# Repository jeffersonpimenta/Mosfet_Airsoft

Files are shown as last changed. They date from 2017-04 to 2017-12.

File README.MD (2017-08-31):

# Gatilho eletrônico para AEGs

Uma opção às encontradas no mercado brasileiro, custo inferior sem perca de qualidade!

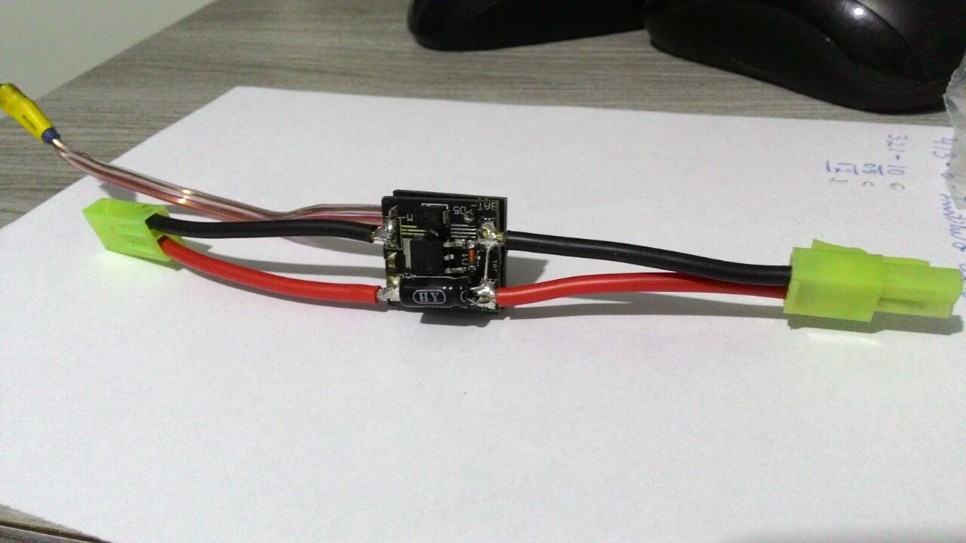
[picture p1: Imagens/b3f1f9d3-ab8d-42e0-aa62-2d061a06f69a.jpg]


## Modos de funcionamento

1. Modo espelhamento: Não faz nenhuma programação no modo de disparo.
2. Modo rajada: Cada toque dispara n tiros configurados
3. Modo econômico: Cada rajada dispara apenas n tiros configurados

## Como configurar

1. Segure o gatilho e conecte a bateria
2. Ao ouvir o primeiro bipe, aperte o gatilho de acordo com o modo desejado (1, 2 ou 3).
3. Segure o gatilho até ouvir um bipe contínuo para confirmar.
4. Se o modo configurado for o 2 ou o 3, precisamos configurar a quantidade de disparos! Ponha a arma no semi-automático e dê dois disparos. Um bipe será ouvido quando a operação for concluída.
5. Aperte o gatilho de acordo com a quantidade de disparos configuradas.
6. Segure até ouvir um bipe contínuo.
7. Feito!

A demonstração pode ser vista [aqui](https://www.youtube.com/watch?v=d0rjX8GWv6M&t=5s)

## Quais as vantagens em relação ao gatilho stock da AEG?

- [x] Evita o desgaste prematuro dos contatos mecânicos
- [x] Leve ganho de cadência
- [x] Uma leve economia de bateria
- [x] Controle total dos disparos

## Arquivos e fotos

* /BRD - Esquemático e desenho da placa
A placa pode ser comprada [aqui](https://www.curtacircuitos.com.br/jeffersonpimenta/Gatilho) 
* /CODE - [Código fonte](https://github.com/jeffersonpimenta/Mosfet_Airsoft/tree/master/Code)
* /Imagens - [Fotos](https://github.com/jeffersonpimenta/Mosfet_Airsoft/tree/master/Imagens)

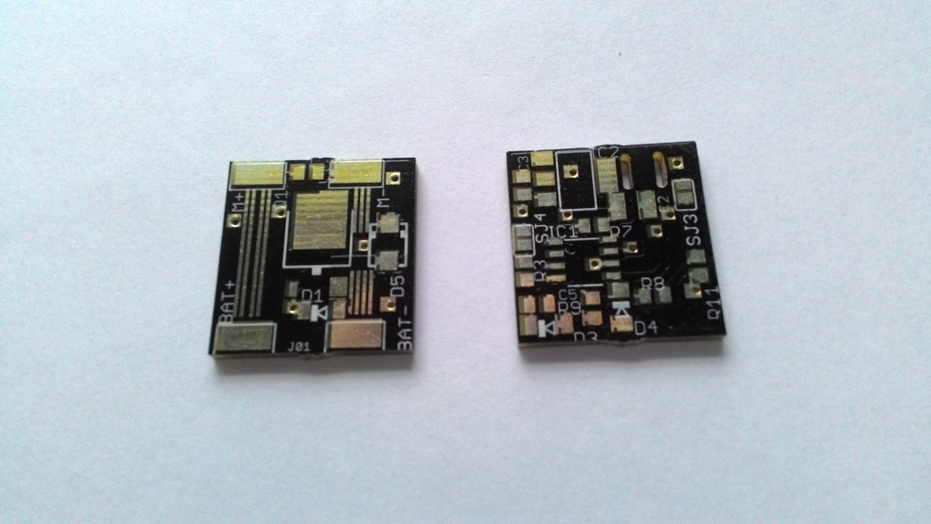
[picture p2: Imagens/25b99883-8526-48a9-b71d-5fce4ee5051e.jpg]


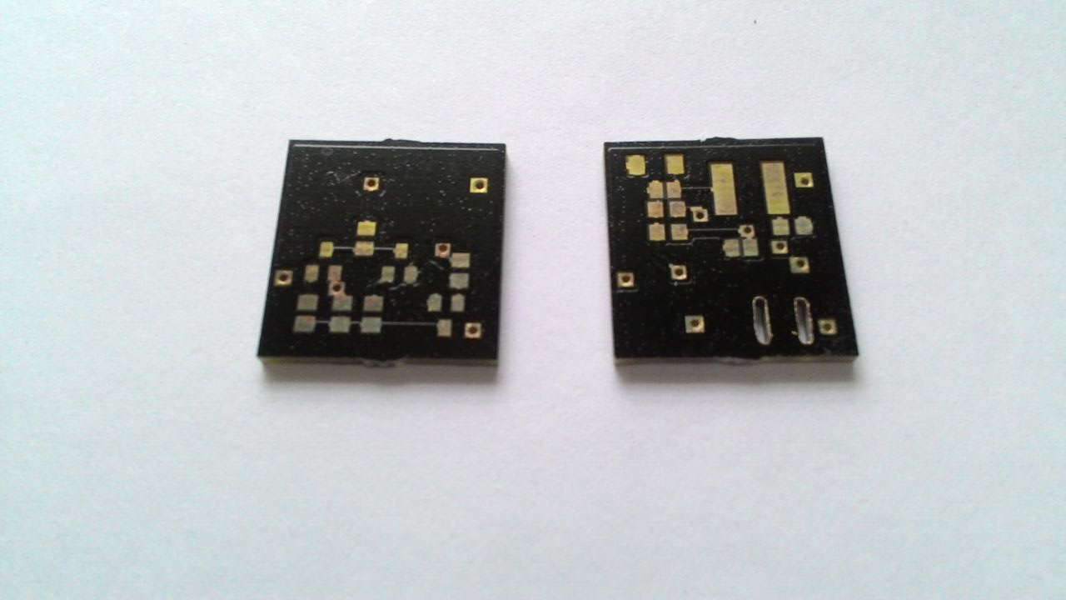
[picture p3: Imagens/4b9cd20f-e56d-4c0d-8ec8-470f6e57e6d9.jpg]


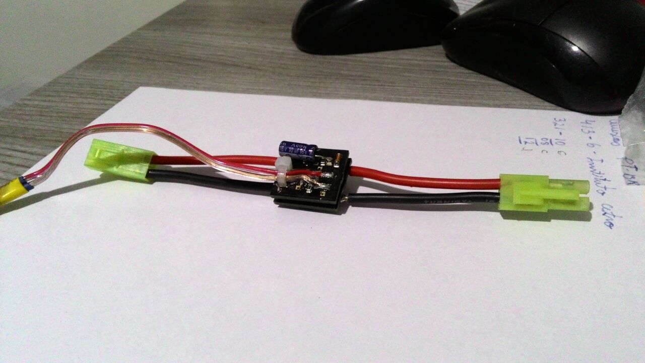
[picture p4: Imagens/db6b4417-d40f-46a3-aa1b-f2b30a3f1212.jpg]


A placa pode ser encomendada pelo link https://www.curtacircuitos.com.br/jeffersonpimenta/Gatilho 

Custa apenas 8,82 reais a unidade e abaixo uma imagem das placas produzidas.

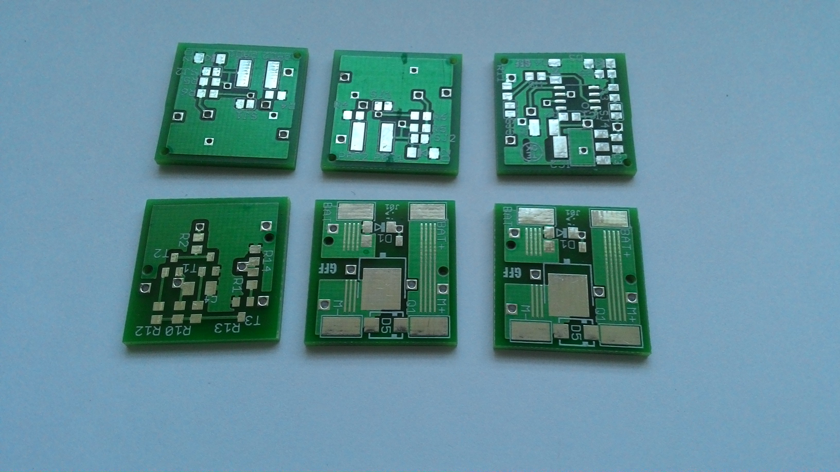
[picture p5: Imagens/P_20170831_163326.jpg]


# Observações
* O microcontrolador que deve ser utilizado tem referência Attiny85, não o Attiny13 como mostrado no esquemático, apenas uma falta da biblioteca para o dispositivo. Ambos são da mesma família e possuem a mesma pinagem
* Utilizar Atmel Studio 7.0

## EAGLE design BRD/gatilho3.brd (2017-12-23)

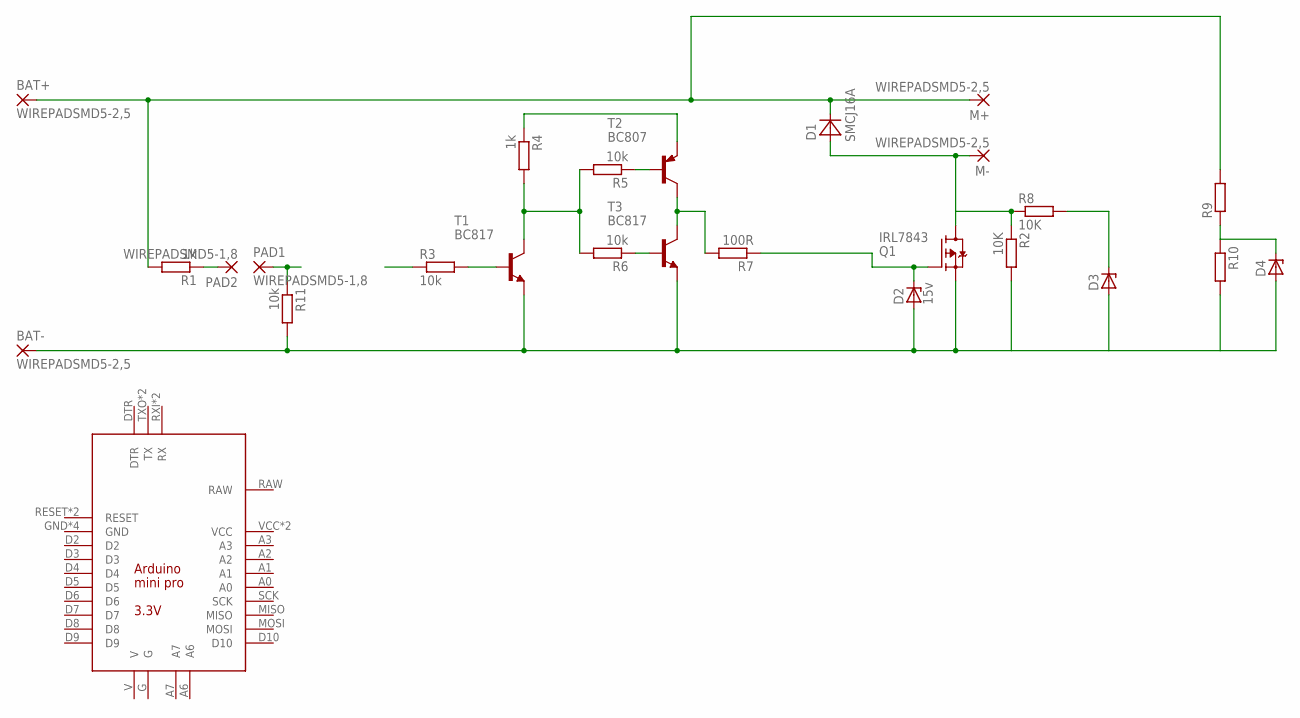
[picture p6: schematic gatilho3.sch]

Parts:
BAT+: WIREPADSMD5-2,5; 5-2,5
BAT-: WIREPADSMD5-2,5; 5-2,5
D1: SMCJ16A; SMA
D2: 15v; SOD80C
D3, D4: ZENER-DIODESOD80C; SOD80C
M+: WIREPADSMD5-2,5; 5-2,5
M-: WIREPADSMD5-2,5; 5-2,5
PAD1, PAD2: WIREPADSMD5-1,8; 5-1,8
Q1: IRL7843; TO252
R1, R4: 1k; R0805
R2, R8: 10K; R0805
R3, R5, R6, R11: 10k; R0805
R7: 100R; R0805
R9, R10: R-EU_R0805; R0805
T1, T3: BC817; SOT23-BEC
T2: BC807; SOT23-BEC
U$1: ARDUINO_MINI_PRO_3V3

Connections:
unnamed: BAT-.1, D2.A, D3.A, D4.A, Q1.2 (S), R2.2, R10.2, R11.2, T1.E, T3.E
unnamed: D1.A, M-.1, Q1.3 (D), R2.1, R8.1
unnamed: D4.C, R9.1, R10.1
unnamed: PAD2.1, R1.1
unnamed: BAT+.1, D1.C, M+.1, R1.2, R9.2
unnamed: PAD1.1, R11.1
unnamed: D3.C, R8.2
unnamed: R4.1, T2.E
unnamed: R4.2, R5.2, R6.2, T1.C
unnamed: R3.2, T1.B
unnamed: R7.2, T2.C, T3.C
unnamed: R5.1, T2.B
unnamed: R6.1, T3.B
unnamed: D2.C, Q1.1 (G), R7.1

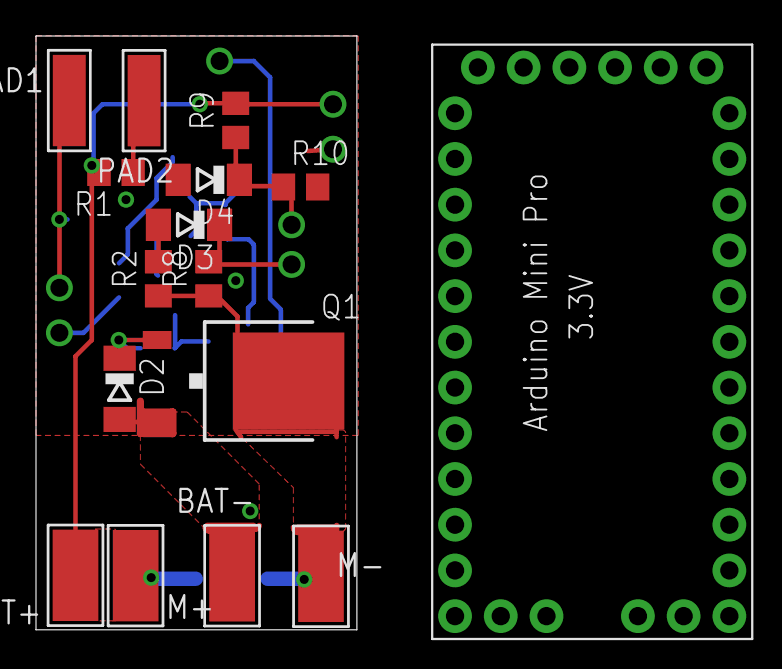
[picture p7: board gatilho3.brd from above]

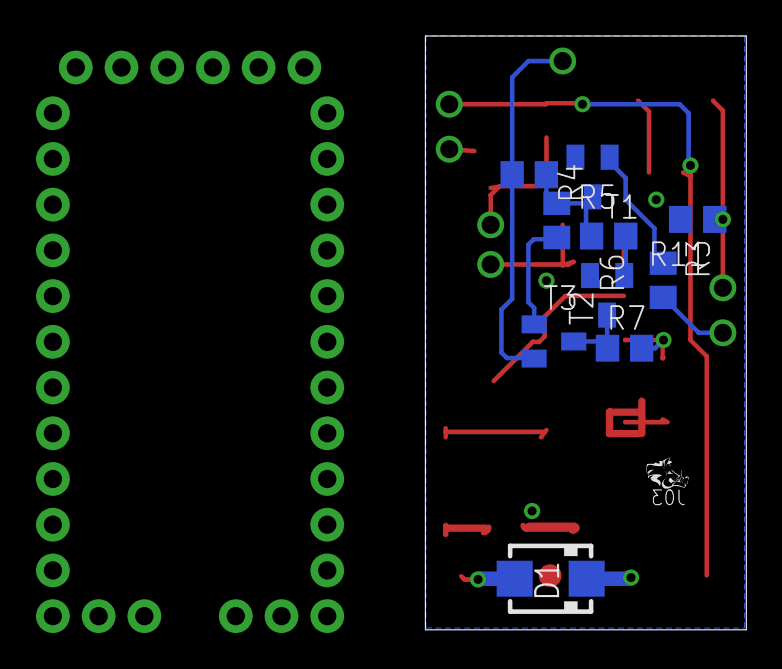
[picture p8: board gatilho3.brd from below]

Board: 2 copper layers, 17.8 x 33.0 mm, 26 parts (10 on the bottom side), 14 nets.

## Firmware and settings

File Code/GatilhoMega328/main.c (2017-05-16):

/*
 * GatilhoMega328.c
 *
 * Created: 12/01/2017 22:06:59
 * Author : Jéfferson
 */ 

//#define F_CPU 9600000UL

#define bit_get(p,m) ((p) & _BV(m))
#define bit_set(p,m) ((p) |= _BV(m))
#define bit_clear(p,m) ((p) &= ~_BV(m))

#include "util/delay.h"
#include <avr/io.h>
#include <avr/pgmspace.h>

#define Ptrigger DDRB
#define Trigger PINB
#define Pintrigger PB1//porta do gatilho

#define Omotor DDRB
#define Motor PORTB
#define Pinmotor PB0//porta do controle do motor

#define atraso 0.9

#define  debouncedelay 5

uint8_t tiros,timeon,firemode=0;//variáveis que deverão ficar na eeprom
uint8_t i,check=0;//seta variáveis

int main(void)
{

	bit_clear(Ptrigger,Pintrigger);//seta ddr do gatilho como entrada
	bit_set(Omotor,Pinmotor);//seta ddr do motor como saída
	bit_clear(Motor,Pinmotor);//garante que o motor ficará desligado
	barulho();
	_delay_ms(200);
	barulho();
	
	
while(1){
	check=0;
	do
	{
		check++;
		_delay_ms(4);
	} while (!bit_get(Trigger,Pintrigger) && (check<200));
	
	if (check<200)
	{
		tiros=eeprom_read_byte((uint8_t*)10);//lê a quantidade de tiros configuradas
		timeon=eeprom_read_byte((uint8_t*)11);//carrega o tempo de tiro da memória
		firemode=eeprom_read_byte((uint8_t*)12);//lê a quantidade de tiros configuradas		
		normal();//funcionamento normal
	}else
	{
		conf();//entra no modo de configuração
	}
}	
	
	
	

}


void normal(){
	uint8_t j=0,i=0;//declara contador
		
		if (firemode==1)
		{
			while(1){
						if (bit_get(Trigger,Pintrigger))
						{
							bit_clear(Motor,Pinmotor);
						}else{
							bit_set(Motor,Pinmotor);
						}
					}
		}//modo de espelhamento do estado do gatilho
		
		
		if (firemode==2){//modo economico
			while(1){
				i=0;
				_delay_ms(1);
				while(!bit_get(Trigger,Pintrigger)){//detecta gatilho pressionado
					i++;
					_delay_ms(1);
					if (i>debouncedelay)
					{
						bit_set(Motor,Pinmotor);//liga motor
						
						if ((!bit_get(Trigger,Pintrigger))){
							for (i=0;i<tiros;i++)//quantidade de tiros menos o efetuado
							{
								
							if (i==0)
								{//primeiro tiro, de aceleração
									for (j=0;j<timeon;j++)
									{
										_delay_ms(1);
									}//tempo que cada ciclo leva pra se completar									
									}else{
									
									if (bit_get(Trigger,Pintrigger)) break;//para se o usuário parar os tiros	
										
									for (j=0;j<(timeon*atraso);j++)
									{
										_delay_ms(1);
									}//tempo que cada ciclo leva pra se completar									
									}//segundo tiro, motor acelerado

								}
							bit_clear(Motor,Pinmotor);//desliga motor, pois os tiros configurados foram efetuados						
	
							do 
							{
								_delay_ms(1);
							} while (!bit_get(Trigger,Pintrigger));//espera o gatilho ser liberado
							
							
						}
					}else bit_clear(Motor,Pinmotor);//desliga motor
				}	
			}
		}
		
		
		if (firemode==3)//modo rambo
		{
			while(1){
				i=0;				
				_delay_ms(1);
				while(!bit_get(Trigger,Pintrigger)){//detecta gatilho pressionado
					i++;
					_delay_ms(1);
					if (i>debouncedelay)
					{
						bit_set(Motor,Pinmotor);//liga motor
						
						if ((!bit_get(Trigger,Pintrigger))){
							for (i=0;i<tiros;i++)//quantidade de tiros efetuado
							{
								if (i==0)
								{//primeiro tiro, de aceleração
																	
									for (j=0;j<timeon;j++)
									{
										_delay_ms(1);
									}//tempo que cada ciclo leva pra se completar
									}else{
									for (j=0;j<(timeon*atraso);j++)
									{
										_delay_ms(1);
									}//tempo que cada ciclo leva pra se completar
								}//segundo tiro, motor acelerado
							}
							
							while(!bit_get(Trigger,Pintrigger)){
								for (j=0;j<(timeon*atraso);j++)
								{
									_delay_ms(1);
								}//tempo que cada ciclo leva pra se completar								
							}
							bit_clear(Motor,Pinmotor);//desliga motor
						
					}
				}else bit_clear(Motor,Pinmotor);//desliga motor
			}
		}	
	}
}



void conf(){
	uint8_t flag=1;
	
	
	firemode=0;//limpa firemode
	flag=1;//reseta flag

	do
	{
		barulho();
	} while (!bit_get(Trigger,Pintrigger));	//espera usuário parar de apertar pra entrar no menu

	
	do
	{
		i=0;//reseta variavel
		while(!bit_get(Trigger,Pintrigger)){
			i++;
			_delay_ms(100);
			if (i>30)//quebra o loop se o gatilho for pressionado
			{
				flag=0;//sinaliza final da função
				if (firemode>3) firemode=1;
				if (firemode==0) firemode=1;//evita treta
				eeprom_write_byte((uint8_t*) 12, firemode);//grava na memo
				break;
			}
		}//conta o tempo que o gatilho foi apertado

		if (i>2)//debounce
		{
			if (i>30)//maior que 4 segundos
			{
				for (i=0;i<firemode;i++)
				{
					barulho();
					_delay_ms(500);//indica o modo configurado
				}
				
				}else{
				firemode++;
			}
		}
	} while (flag);//loop de configuração do modo	


	do
	{
		barulho();
	} while (!bit_get(Trigger,Pintrigger));	//espera usuário parar de apertar pra sair do menu
	
	if (firemode!=1)
	{
		
		flag=1;//seta flag do loop

		
		do{
			i=0;
			while(!bit_get(Trigger,Pintrigger)){//detecta gatilho pressionado
				i++;
				_delay_ms(1);
				if (i>debouncedelay)
				{
					bit_set(Motor,Pinmotor);//liga motor
					do
					{
						i++;
						_delay_ms(1);
					} while (!bit_get(Trigger,Pintrigger));
					bit_clear(Motor,Pinmotor);//desliga motor
					flag=0;
				}
			}//dois tiros pra configurar o tempo de tiro
			
			}while(flag);
			
		
		flag=1;//seta flag do loop
		do 
		{
				i=0;
				while(!bit_get(Trigger,Pintrigger)){//detecta gatilho pressionado
					i++;
					_delay_ms(1);
					if (i>debouncedelay)
					{			
						bit_set(Motor,Pinmotor);//liga motor		
						do 
						{
							i++;
							_delay_ms(1);
						} while (!bit_get(Trigger,Pintrigger));
						bit_clear(Motor,Pinmotor);//desliga motor
					
						flag=0;//avisa que houve um pressionamento válido		
						eeprom_write_byte((uint8_t*) 11, i);//salva o delay na eeprom	
						timeon=i;//atualiza variável			
					}
				}
			
		} while (flag);//loop de configuração de tempo de disparo


		_delay_ms(1000);
		do
		{
			barulho();
		} while (!bit_get(Trigger,Pintrigger));//não sai da função até que o gatilho seja liberado
	
	flag=1;//reseta flag	
	tiros=0;
	
		do
		{
			i=0;//reseta variavel
			while(!bit_get(Trigger,Pintrigger)){
				i++;
				_delay_ms(100);			
				if (i>30)
				{
					if (tiros==0) tiros=3;//evita que nenhuma info inválida passe à frente
					flag=0;//sinaliza final da função
					eeprom_write_byte((uint8_t*) 10, tiros);//grava na memo
					break;
				}//se for segurado o gatilho, quebra o loop
			}//conta o tempo que o gatilho foi apertado
		
			if (i>2)//debounce
			{
				if (i>30)//maior que 4 segundos
				{
					for (i=0;i<tiros;i++)
					{
						barulho();
						_delay_ms(500);//indica a quantidade de tiros configuradas
					}
				
				}else tiros++;
			}
		
		
		} while (flag);//loop de configuração de quantidade de disparos

	
		do
		{
			barulho();
		} while (!bit_get(Trigger,Pintrigger));//não sai da função até que o gatilho seja liberado	
	}
}


void barulho(){
				for (uint8_t k=0;k<50;k++)
				{
					bit_set(Motor,Pinmotor);
					_delay_us(100);
					bit_clear(Motor,Pinmotor);
					_delay_ms(1);
				}//faz barulho
}

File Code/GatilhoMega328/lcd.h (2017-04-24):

/****************************************************************************
  Jéfferson Pimenta
  */

#ifndef F_CPU
#define F_CPU 4000000UL
#endif

#include <avr/io.h>
#include <util/delay.h>

// especifique as portas de conexão do lcd
#define lcd_D7_port     PORTB                   // lcd D7
#define lcd_D7_bit      PORTB5
#define lcd_D7_ddr      DDRB

#define lcd_D6_port     PORTB                   // lcd D6
#define lcd_D6_bit      PORTB4
#define lcd_D6_ddr      DDRB

#define lcd_D5_port     PORTB                   // lcd D5
#define lcd_D5_bit      PORTB3
#define lcd_D5_ddr      DDRB

#define lcd_D4_port     PORTB                   // lcd D4
#define lcd_D4_bit      PORTB2
#define lcd_D4_ddr      DDRB

#define lcd_E_port      PORTB                   // lcd Enable
#define lcd_E_bit       PORTB1
#define lcd_E_ddr       DDRB

#define lcd_RS_port     PORTB                   // lcd RS
#define lcd_RS_bit      PORTB0
#define lcd_RS_ddr      DDRB

// LCD module information
#define lcd_LineOne     0x00                    // start of line 1
#define lcd_LineTwo     0x40                    // start of line 2
//#define   lcd_LineThree   0x14                  // start of line 3 (20x4)
//#define   lcd_lineFour    0x54                  // start of line 4 (20x4)
//#define   lcd_LineThree   0x10                  // start of line 3 (16x4)
//#define   lcd_lineFour    0x50                  // start of line 4 (16x4)

// LCD instructions
#define lcd_Clear           0b00000001          // replace all characters with ASCII 'space'
#define lcd_Home            0b00000010          // return cursor to first position on first line
#define lcd_EntryMode       0b00000110          // shift cursor from left to right on read/write
#define lcd_DisplayOff      0b00001000          // turn display off
#define lcd_DisplayOn       0b00001100          // display on, cursor off, don't blink character
#define lcd_FunctionReset   0b00110000          // reset the LCD
#define lcd_FunctionSet4bit 0b00101000          // 4-bit data, 2-line display, 5 x 7 font
#define lcd_SetCursor       0b10000000          // set cursor position
#define Set_blink_on        0b00001111
#define Set_blink_off       0b00001100


// Function Prototypes





/*============================== 4-bit LCD Functions ======================*/
/*
  Name:     lcd_init
  Purpose:  initialize the LCD module for a 4-bit data interface
  Entry:    equates (LCD instructions) set up for the desired operation
  Exit:     no parameters
  Notes:    uses time delays rather than checking the busy flag
*/
void lcd_init(void)
{
	
	// configure the microprocessor pins for the data lines
	lcd_D7_ddr |= (1<<lcd_D7_bit);                  // 4 data lines - output
	lcd_D6_ddr |= (1<<lcd_D6_bit);
	lcd_D5_ddr |= (1<<lcd_D5_bit);
	lcd_D4_ddr |= (1<<lcd_D4_bit);

	// configure the microprocessor pins for the control lines
	lcd_E_ddr |= (1<<lcd_E_bit);                    // E line - output
	lcd_RS_ddr |= (1<<lcd_RS_bit);                  // RS line - output
	
	
// Power-up delay
    _delay_ms(100);                                 // initial 40 mSec delay

// IMPORTANT - At this point the LCD module is in the 8-bit mode and it is expecting to receive  
//   8 bits of data, one bit on each of its 8 data lines, each time the 'E' line is pulsed.
//
// Since the LCD module is wired for the 4-bit mode, only the upper four data lines are connected to 
//   the microprocessor and the lower four data lines are typically left open.  Therefore, when 
//   the 'E' line is pulsed, the LCD controller will read whatever data has been set up on the upper 
//   four data lines and the lower four data lines will be high (due to internal pull-up circuitry).
//
// Fortunately the 'FunctionReset' instruction does not care about what is on the lower four bits so  
//   this instruction can be sent on just the four available data lines and it will be interpreted 
//   properly by the LCD controller.  The 'lcd_write_4' subroutine will accomplish this if the 
//   control lines have previously been configured properly.

// Set up the RS and E lines for the 'lcd_write_4' subroutine.
    lcd_RS_port &= ~(1<<lcd_RS_bit);                // select the Instruction Register (RS low)
    lcd_E_port &= ~(1<<lcd_E_bit);                  // make sure E is initially low

// Reset the LCD controller
    lcd_write_4(lcd_FunctionReset);                 // first part of reset sequence
    _delay_ms(10);                                  // 4.1 mS delay (min)

    lcd_write_4(lcd_FunctionReset);                 // second part of reset sequence
    _delay_us(200);                                 // 100uS delay (min)

    lcd_write_4(lcd_FunctionReset);                 // third part of reset sequence
    _delay_us(200);                                 // this delay is omitted in the data sheet

// Preliminary Function Set instruction - used only to set the 4-bit mode.
// The number of lines or the font cannot be set at this time since the controller is still in the
//  8-bit mode, but the data transfer mode can be changed since this parameter is determined by one 
//  of the upper four bits of the instruction.
 
    lcd_write_4(lcd_FunctionSet4bit);               // set 4-bit mode
    _delay_us(80);                                  // 40uS delay (min)

// Function Set instruction
    lcd_write_instruction(lcd_FunctionSet4bit);   // set mode, lines, and font
    _delay_us(80);                                  // 40uS delay (min)

// The next three instructions are specified in the data sheet as part of the initialization routine, 
//  so it is a good idea (but probably not necessary) to do them just as specified and then redo them 
//  later if the application requires a different configuration.

// Display On/Off Control instruction
    lcd_write_instruction(lcd_DisplayOff);        // turn display OFF
    _delay_us(80);                                  // 40uS delay (min)

// Clear Display instruction
    lcd_write_instruction(lcd_Clear);             // clear display RAM
    _delay_ms(4);                                   // 1.64 mS delay (min)

// ; Entry Mode Set instruction
    lcd_write_instruction(lcd_EntryMode);         // set desired shift characteristics
    _delay_us(80);                                  // 40uS delay (min)

// This is the end of the LCD controller initialization as specified in the data sheet, but the display
//  has been left in the OFF condition.  This is a good time to turn the display back ON.
 
// Display On/Off Control instruction
    lcd_write_instruction(lcd_DisplayOn);         // turn the display ON
    _delay_us(80);                                  // 40uS delay (min)
}
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
